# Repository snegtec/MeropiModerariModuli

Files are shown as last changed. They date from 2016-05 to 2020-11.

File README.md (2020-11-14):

/*****************************************************************************
*
* MEROPI MODERARI MODULI
* a simple microcontroller system for controlling light output of linear 
* fluorescent tube according to saved program
* 
* version: 0.3 (November 2020)
* author: Erik Kos
*   snegtec.com
*   snegtec@outlook.com
* 
* Copyright (c) 2014-2020 Erik Kos
* License:
*   application, source code - GNU General Public License
*   hardware (schematics, pcb design) - Creative Commons Attribution 
*   Share-Alike license (CC BY-SA 4.0)
* 
****************************************************************************/

Used tools
* compiler: Atmel Studio 6
* application for pcb design: Eagle 6.5.0.

Notes
* this is a beta version!
* pcb for power and relay modules are one-sided; you can create it cheaper than 2 sided versions.

Important note!
* The power module use 230V. There could requirements in your country about design and electrical rules for design of such devices. If you are not confident when working with such voltages don't use the power module. Use ready power supply. 

TODO
* it is better to use external oscilator
* it would be good idea to add socket for serial (txd, rxd); for example during reset Bluetooth connection is lost; it is not a problem in final, production environment but during debug it bothers;
* holes for mounting the boards could have bigger diameter
* cloud events hasn't been tested too carefully; only PWM1 pin has support for cloud events
* no support for daylight saving time 
* add more meaningful captions for elements on pcb boards; like 5V or 3,3V instead of X5 or X3;

Bugs
* There is support for bigger buffer for transmission of AT commands. But sometimes there is a problem that the end of the line disapears when parsed.

Bootloader information
* My version of module uses ATMEL AVR UART Bootloader for AVR-GCC/avr-libc. It is not needed for modules to work. But it can be very helpful to update software when a final module is mounted in a place where there is difficult access.

* MMM software has support for butterfly compatible programmer. It allows for touchless programming of the module. No need to press any button before programming the device. Programmer needs just to use Bluetooth serial port. You start programming, the module resets and bootloader loads into memory and loads new program to memory. More info in utils_com.c file on line 536.

More information about bootloader:
* ATMEL AVR UART Bootloader for AVR-GCC/avr-libc
* by Martin Thomas, Kaiserslautern, Germany
* mthomas@rhrk.uni-kl.de
* eversmith@heizung-thomas.de
* http://www.siwawi.arubi.uni-kl.de/avr_projects

/****************************************************************************/

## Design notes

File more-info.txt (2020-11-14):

/****************************************************************************/

Meropi Moderari Moduli

Simple microcontroller system for controlling light output of linear fluorescent tube according to saved program
Introduction

I needed a way for adjusting the output of light of linear fluorescent tubes. I needed a system which allows me to program light level for specified hour. It had to be a system for simulating day. For example: at 6 o'clock the light is enabled but is weak. So up to 8 o'clock the light level rises slowly and it stays at specified value until 18 o'clock. Then it diminishes. And at 20 o'clock the light is turn off.

So what I really wanted was a computer system. There weren't any market solution which suits me. The current existing systems was costly, difficult to use or limited. I decided to create my own solution. I chose to use din enclosures. It is tidy and clean way for electronic to be contained within. No need to design special boxes and cut holes in it. Usually fluorescent tubes don't diminish the light by itself. So I needed a special electronic ballast with function to reduce the light level. The chosen one used common 1-10V system.

I like systems which are flexible and easy to use. I am a programmer so I am not limited to "(not) easy to use" user's interfaces. I wanted a system created by a programmer for use by a programmer. Why add physical buttons, lcd displays if there is much simpler solution? I used Bluetooth connectivity with its Serial Port Profile. This is the most simple and effective solution. Because a device can be controlled by Android phone or notebook. It gives possibility to make advanced functions with keeping in mind real easiness of software controls like buttons, radio and check boxes, edit boxes, lists and even sliders. And creating sophisticated desktop/mobile application is usually much simpler than creating traditional user interface with buttons, lcd displays and led diodes. 
Hardware

The hardware is divided into 3 din units. There is special control unit. It contains microcontroller (ATmega328P) with some additional components: micro-sd socket, real time clock (PCF8563) and HC05 bluetooth module which is connected with serial port of microcontroller. Micro-sd socket was added as a way of expanding memory for data. But it is not used in this application. There is 14 input/output lines. Some of them can be used as SPI and I2C lines. Four of them are used as PWM channels.

The second din unit serves as a power unit. It is equipped with transformer which lowers voltage. It provides 3 lines of voltage: double 5V and 3,3V thanks of two 78L05F and TS520533 voltage regulators. The third unit contains two relays and two special voltage regulators. 1-10V electronic ballasts are driven by them. All connections are done with 3,5mm terminal blocks. Relays use 5mm terminal blocks. So during assembly in final din box there is no need to use solder iron - just a screwdriver.
Electronics inside
Software

First programming of the central unit has to be done with standard ISP programmer. There was added a bootloader so all next software updates can be made using Bluetooth. Modules may be mounted in place where there is no easy access. So there is no need to press a button (or do something else on device) to enable to upload new software - just restart the module and upload new software.

To use the device there is need to enter user defined set of on/off events. The default method uses terminal emulator. The user sends special AT commands to program date, time, events and lists previously programmed events or clear them. As of time of creating the solution I decided to not create special desktop application for a user. For me it was enough, and very comfortable to use terminal emulator. AT commands are good link between a microcontroller system and application with a graphical user interface. So I have just created simplified Android application. It enables a user to control level of light and there is possible to turn on and off light with a mobile phone.
The application for Android phones
Other features

Finally, I added so called cloud events to the system. If a cloud covers Sun there is a smaller amount of light. But the clouds aren't usually uniform. So the light level changes constantly. Sometimes there are more clouds in the sky and sometimes there are just few clouds on it. So the cloud events simulate the light level change during cloudy day.

Possible uses for such device are: light control, light control for an aquarium or a terrarium, industry applications, data gathering with wireless download and probably many others.
Din modules
Additional information

Used fluorescent tubes were: OSRAM Lumilux T5 HE 880

with 1-10V dimmable starter: b,a,g, BCD35.2F-01/220-240/1-10V
Examples of AT commands

set time

AT+TIME=15:28:00

check what date is on the device

AT+DATE?

List all on/off/pwm (cloud) events

AT+PRINT_EVENTS

clear events

AT+CLEAR_EVENTS

set EXP0 pin output enabled and PWM0 pin output to 127 (50%)

AT+EXP0=1&PWM0=127

add a program and enable automatic (events) mode

AT+ADD=EXP0;0830;HIGH&ADD=PWM0;0830;0;100;60&ADD=PWM0;2050;100;-100;60&ADD=EXP0;2130;LOW&EVENT_MODE

Copyright (c) 2014-2020 Erik Kos

/****************************************************************************/

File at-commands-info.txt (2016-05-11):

	************
	* Information commands

command: AT
response: OK

command: AT+MEROPE
response: MEROPE OK

	************
	* time&date commands

command: AT+DATE?
response: current date set on device

command: AT+TIME?
response: current time set on device

	Setting time and date

command: AT+DATE=YYYY/MM/DD/W_D
example: AT+DATE=2014/10/29/3
year - 4 digits, month and day are 2 digits, week_day is 1 digit

command: AT+DATE=2014/02/07/0
20141029 => wednesday => week_day == 3

command: AT+TIME=HH:MM:SS
example: AT+TIME=21:14:45
always 2 digits for every number: AT+TIME=03:05:07

	************
	* setting pins manually

Set pin EXP0 to high state
command: AT+EXP0=1

Set pin EXP0 to low state
command: AT+EXP0=0

Set PWM0 pin to 45% (pulse width modulation)
AT+PWM0=45

Set PWM0 pin to 100% (100% really means this pin is just high)
AT+PWM0=100

	************
	* event commands

Set device to manual mode. Device's pins are set manually without using a program.
command: AT+MANUAL_MODE

Set device to automatic (events) mode; Device pins are set automatically according to a program on a device.
command: AT+EVENT_MODE

Prints all events
command: AT+PRINT_EVENTS

Clear all events
command: AT+CLEAR_EVENTS

	************
	* adding events

These are commands used to add events to a memory. 

For adding commands it is important to set manual mode and clear earlier events:
command: AT+MANUAL_MODE&CLEAR_EVENTS

Add entry: set EXP0 pin to high at 8:30 every morning
command: ADD=EXP0;0830;HIGH

Add PWM event
command: AT+ADD=pwm_pin;start_time;start_value;end_value;duration
example: AT+ADD=PWM0;0830;0;100;60
explanation: for PWM0 start at 8:30 at 0% and increase pwm value to 100% in 60 minutes
note: duration is always minute; 

Add negative PWM event
if you want to decrease value use negative value
command: ADD=PWM0;1930;100;-100;60
explanation: for PWM0 start at 1930 at 100% and decrease pwm value 100% below current in 60 minutes

	Important information

Note: Added events has to be sorted by time.

This is ok (first event at 10:00, later event at 12:30)
AT+ADD=EXP0;1000;HIGH&ADD=EXP0;1230;LOW

This is wrong
AT+ADD=EXP0;1230;LOW&ADD=EXP0;1000;HIGH

	************
	* Example program:

This is an example program. It is used to control light level of fluorescent tube. A relay used to enable/disable power is controlled by EXP0 pin of MMM module. The light level is controlled by driving the circuit by PWM0 pin of the module.

The program: 
 - the light slowly increases from dark to full light in one hour between 8:30 and 9:30
 - the light level is 100% between 9:30 and 19:30
 - the light is dimmed from 100% to 0% between 19:30 and 20:30
 - the light is disabled between 20:30 (evening) and 8:30 (morning)
 - if you restart device during program, it always checks what is the current mode

Note: You may enter several commands at once. But char buffer is limited so don't add too long commands.

AT+ADD=EXP0;0830;HIGH&ADD=PWM0;0830;0;100;60&ADD=PWM0;1930;100;-100;60&ADD=EXP0;2030;LOW&EVENT_MODE

	What does the program do?

beginning of every AT command
command: AT+

set pin EXP0 to high
command: ADD=EXP0;0830;HIGH

set PWM0 pin to: 0% at 8:30 and in 60 minutes increase to 100%
command: ADD=PWM0;0830;0;100;60

set PWM0 pin to 100% at 19:30 and in 60 minutes decrease it to 0% 
command: ADD=PWM0;1930;100;-100;60

set EXP0 pin to low state
command: ADD=EXP0;2030;LOW

enable event mode (runs the program)
command: EVENT_MODE

	************
	* cloud events

command: AT+CLOUD=pin;time;pin_state;duration;final_state
example: AT+CLOUD=PWM1;1530;30;50;30

	************
	* other commands

get and reset VL_BIT (in PCF8563)
command: AT+GET_VL
response: status of VL_BIT

command: AT+RESET_VL
response: resets VL_BIT

	************
	* Control commands

command: AT+RESET
response: reset of device

	************
	* HC-05 configuration

Note: AT+PASS=AT+COMMAND passes AT commands directly to HC-05 BT

command: AT+PASS=AT+PSWD=1357

default pswd: 1234

Change Bluetooth name
command: AT+PASS=AT+NAME=Merope

Get Bluetooth name:
command: AT+PASS=AT+NAME?

Other commands:

Passes AT command to HC-05
command: AT+PASS=AT

Get state of HC-05
command: AT+PASS=AT+STATE?

Get version of HC-05
command: AT+PASS=AT+VERSION?

	************

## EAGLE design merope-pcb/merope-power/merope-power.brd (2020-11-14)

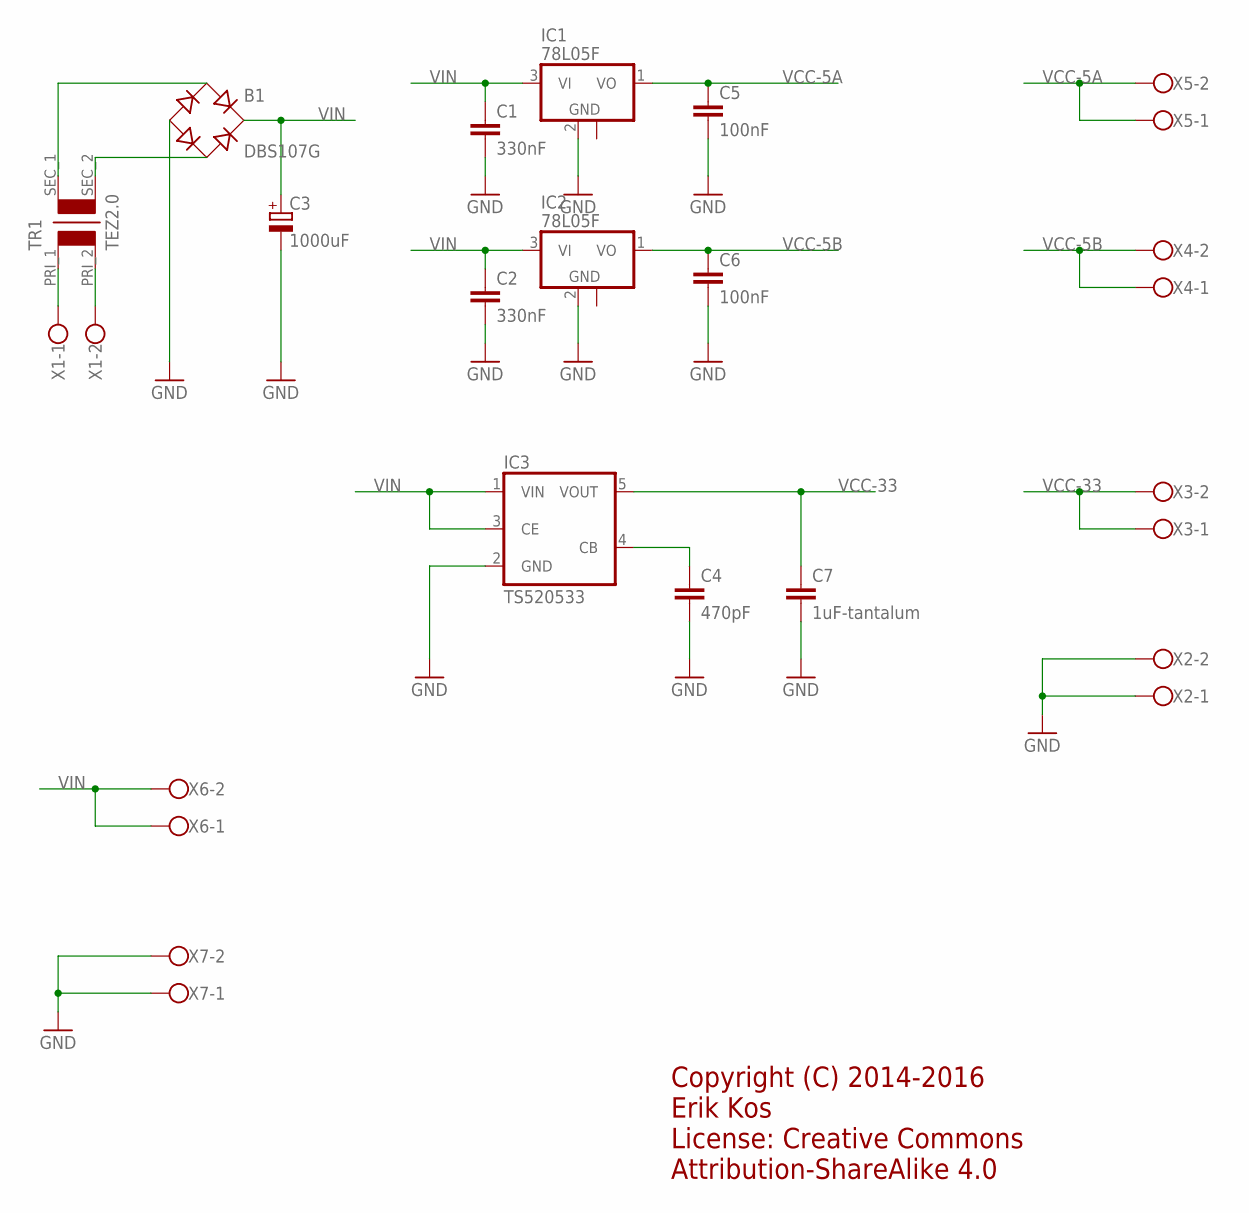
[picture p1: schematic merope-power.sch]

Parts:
B1: DBS107G; DBS
C1, C2: 330nF; C0805
C3: 1000uF; TT5D11
C4: 470pF; C0805
C5, C6: 100nF; C0805
C7: 1uF-tantalum; C0805
IC1, IC2: 78L05F; SOT89
IC3: TS520533; SOT25
TR1: TEZ2.0
X1: TERMINAL_BLOCK_5_2
X2, X3, X4, X5, X6, X7: TERMINAL_BLOCK_35_2

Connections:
GND: B1.-, C1.2, C2.2, C3.-, C4.2, C5.2, C6.2, C7.2, IC1.2 (GND), IC2.2 (GND), IC3.2 (GND), X2.1, X2.2, X7.1, X7.2
unnamed: B1.AC1, TR1.SEC_1
unnamed: C4.1, IC3.4 (CB)
unnamed: B1.AC2, TR1.SEC_2
unnamed: TR1.PRI_1, X1.1
unnamed: TR1.PRI_2, X1.2
VCC-5A: C5.1, IC1.1 (VO), X5.1, X5.2
VCC-5B: C6.1, IC2.1 (VO), X4.1, X4.2
VCC-33: C7.1, IC3.5 (VOUT), X3.1, X3.2
VIN: B1.+, C1.1, C2.1, C3.+, IC1.3 (VI), IC2.3 (VI), IC3.1 (VIN), IC3.3 (CE), X6.1, X6.2

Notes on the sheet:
Copyright (C) 2014-2016 Erik Kos License: Creative Commons Attribution-ShareAlike 4.0

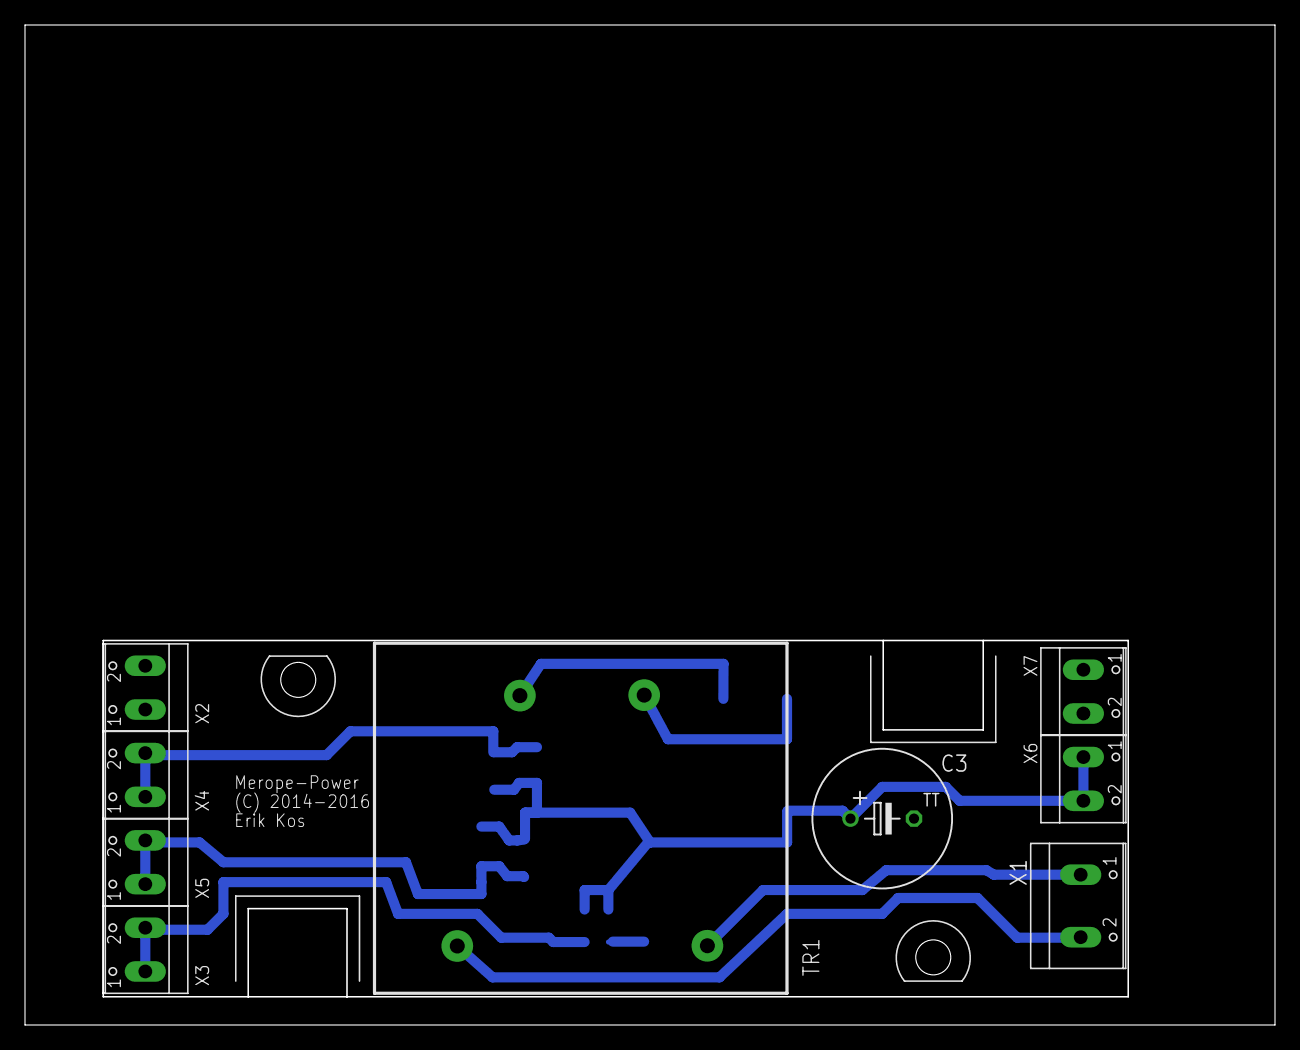
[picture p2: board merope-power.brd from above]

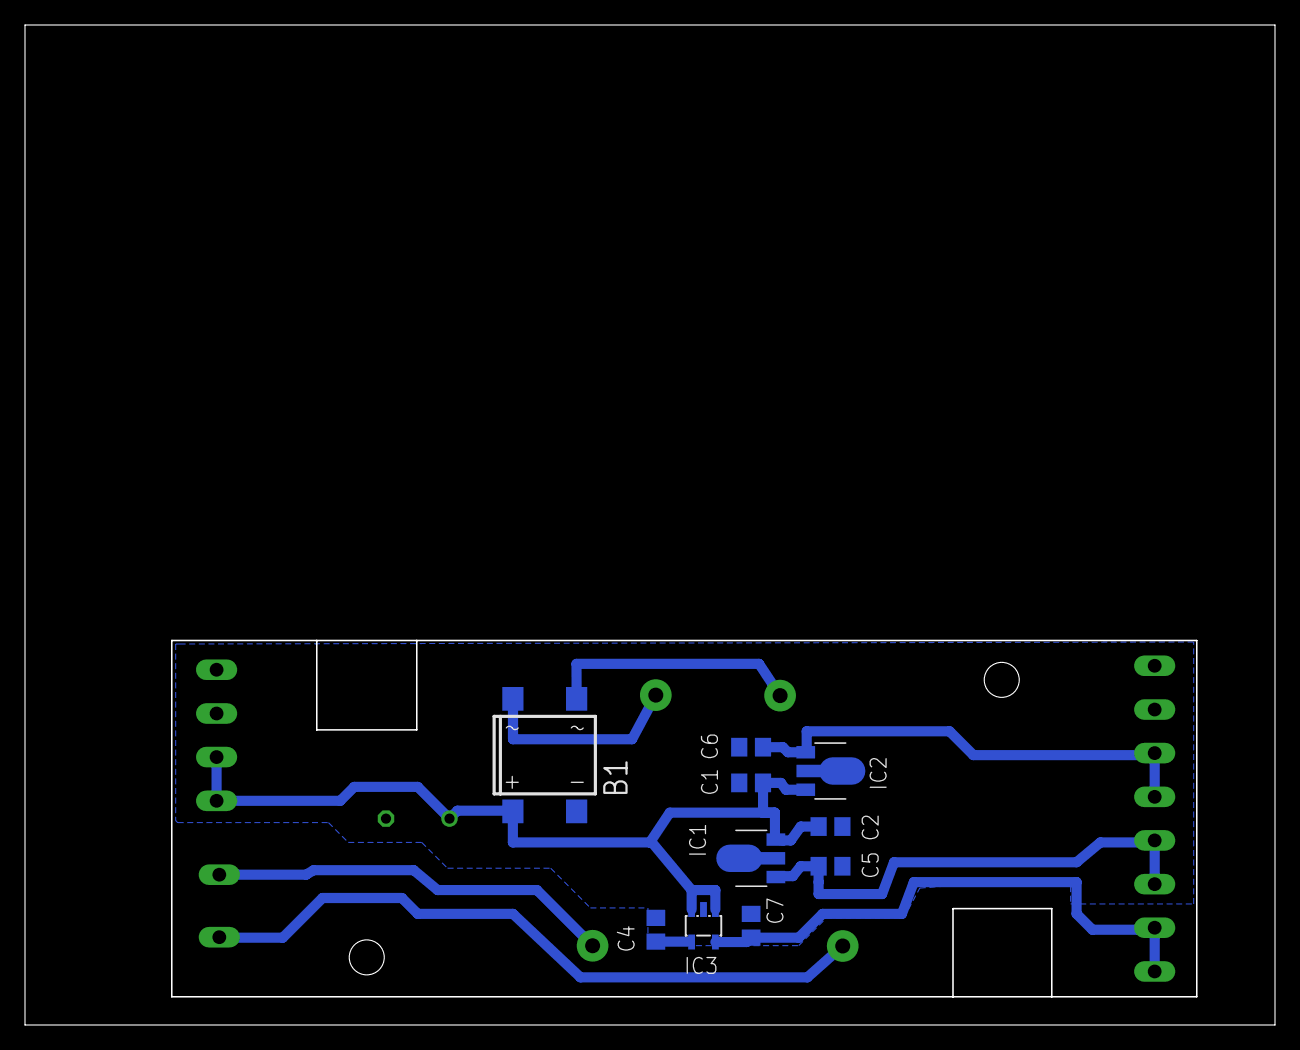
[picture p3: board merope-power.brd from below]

Board: 2 copper layers, 100.0 x 80.0 mm, 20 parts (10 on the bottom side), 10 nets.

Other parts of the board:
U$1: Z-103

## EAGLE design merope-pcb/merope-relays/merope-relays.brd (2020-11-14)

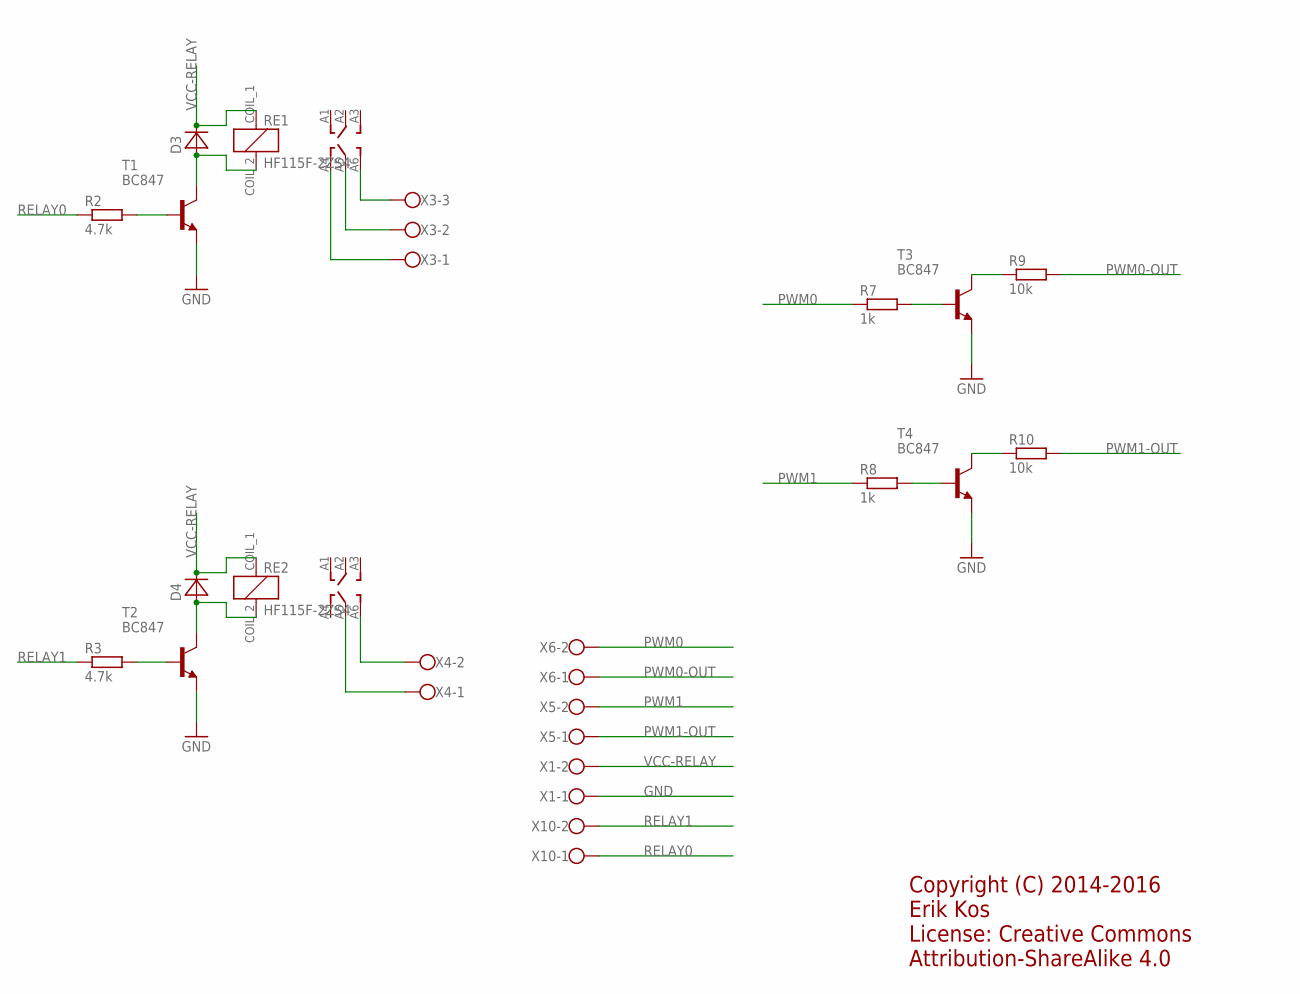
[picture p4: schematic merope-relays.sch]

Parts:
D3, D4: DIODE_0805; R0805
R2, R3: 4.7k; M0805
R7, R8: 1k; M0805
R9, R10: 10k; M0805
RE1, RE2: HF115F-2ZS4; HF115F
T1, T2, T3, T4: BC847; SOT23-BEC
X1, X5, X6, X10: TERMINAL_BLOCK_35_2
X3: TERMINAL_BLOCK_5_3
X4: TERMINAL_BLOCK_5_2

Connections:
GND: T1.E, T2.E, T3.E, T4.E, X1.1
unnamed: RE2.A6, X4.2
unnamed: R2.2, T1.B
unnamed: RE1.A6, X3.3
unnamed: RE1.A5, X3.2
unnamed: D3.1 (A), RE1.COIL_2, T1.C
unnamed: RE2.A5, X4.1
unnamed: RE1.A4, X3.1
unnamed: R3.2, T2.B
unnamed: D4.1 (A), RE2.COIL_2, T2.C
unnamed: R7.2, T3.B
unnamed: R9.1, T3.C
unnamed: R8.2, T4.B
unnamed: R10.1, T4.C
PWM0: R7.1, X6.2
PWM0-OUT: R9.2, X6.1
PWM1: R8.1, X5.2
PWM1-OUT: R10.2, X5.1
RELAY0: R2.1, X10.1
RELAY1: R3.1, X10.2
VCC-RELAY: D3.2 (C), D4.2 (C), RE1.COIL_1, RE2.COIL_1, X1.2

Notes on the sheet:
Copyright (C) 2014-2016 Erik Kos License: Creative Commons Attribution-ShareAlike 4.0

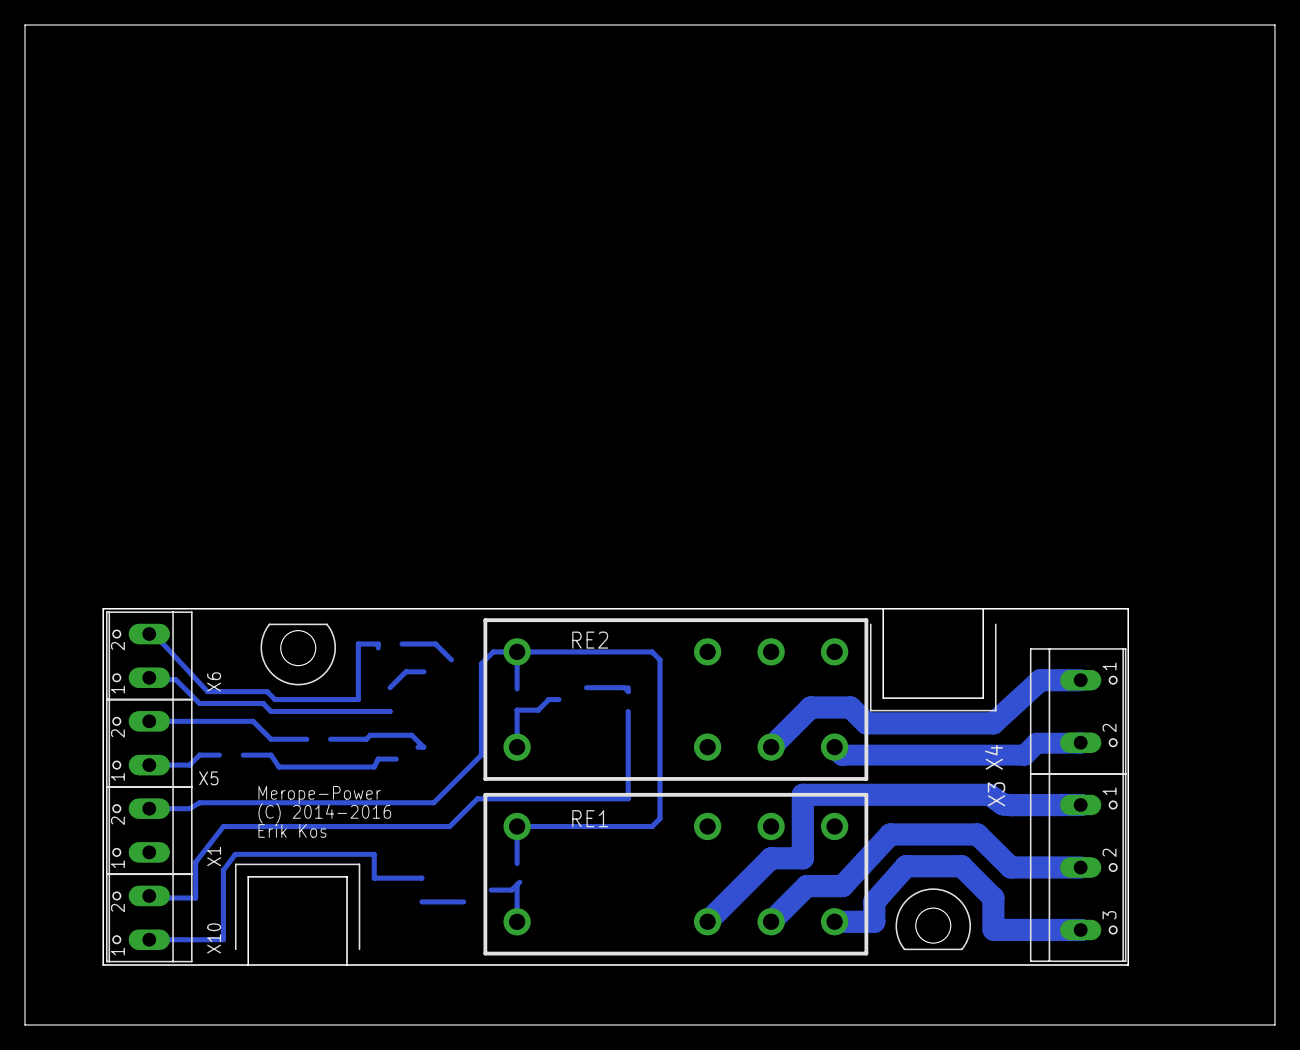
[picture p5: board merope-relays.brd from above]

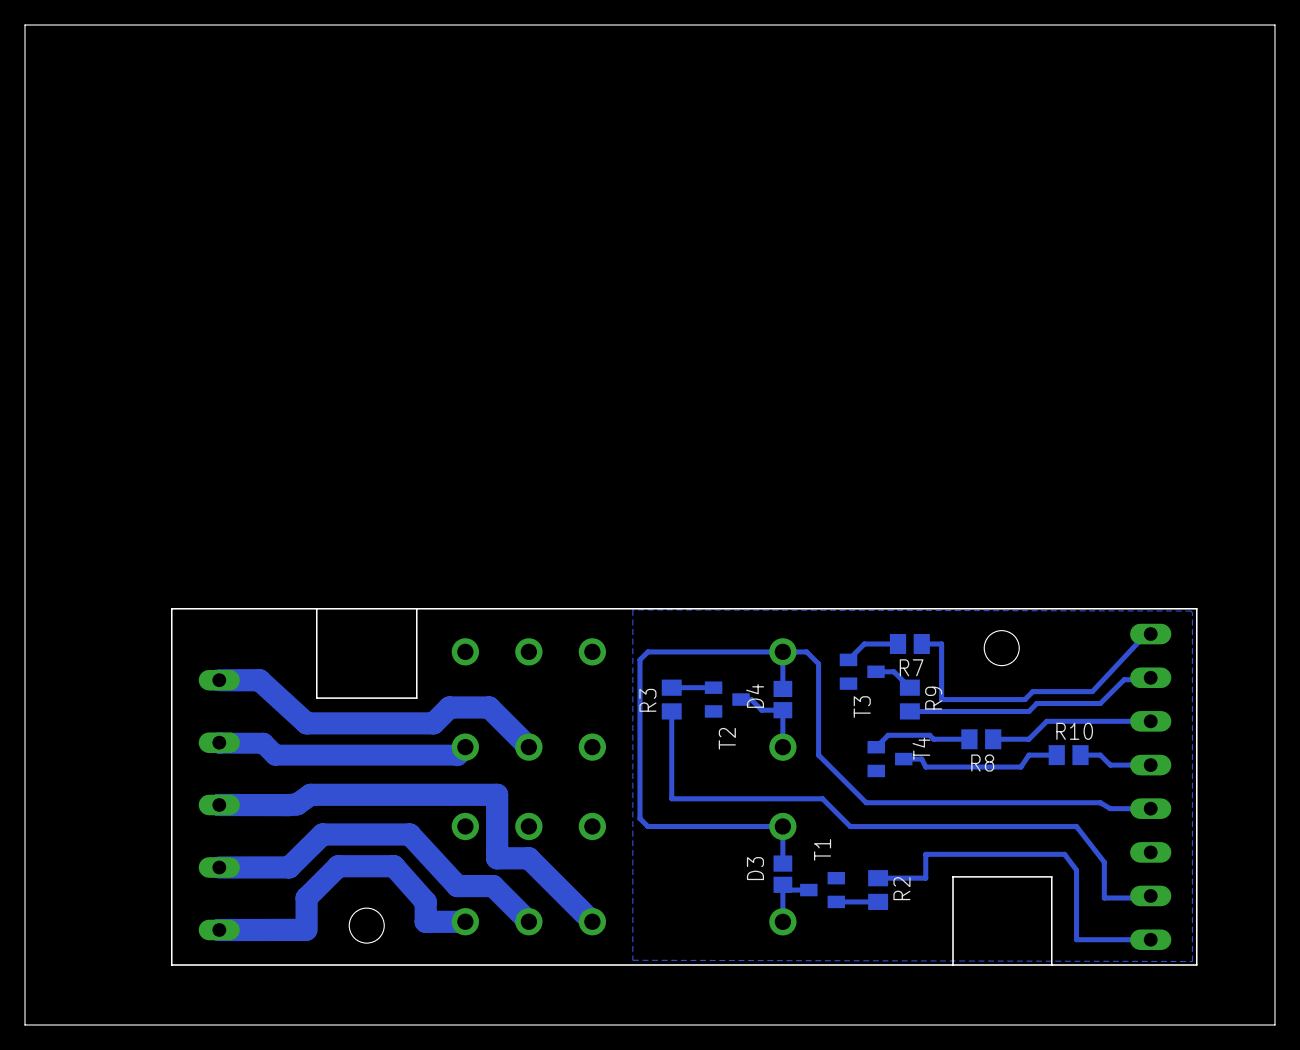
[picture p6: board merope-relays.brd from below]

Board: 2 copper layers, 100.0 x 80.0 mm, 21 parts (12 on the bottom side), 21 nets.

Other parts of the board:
U$1: Z-103

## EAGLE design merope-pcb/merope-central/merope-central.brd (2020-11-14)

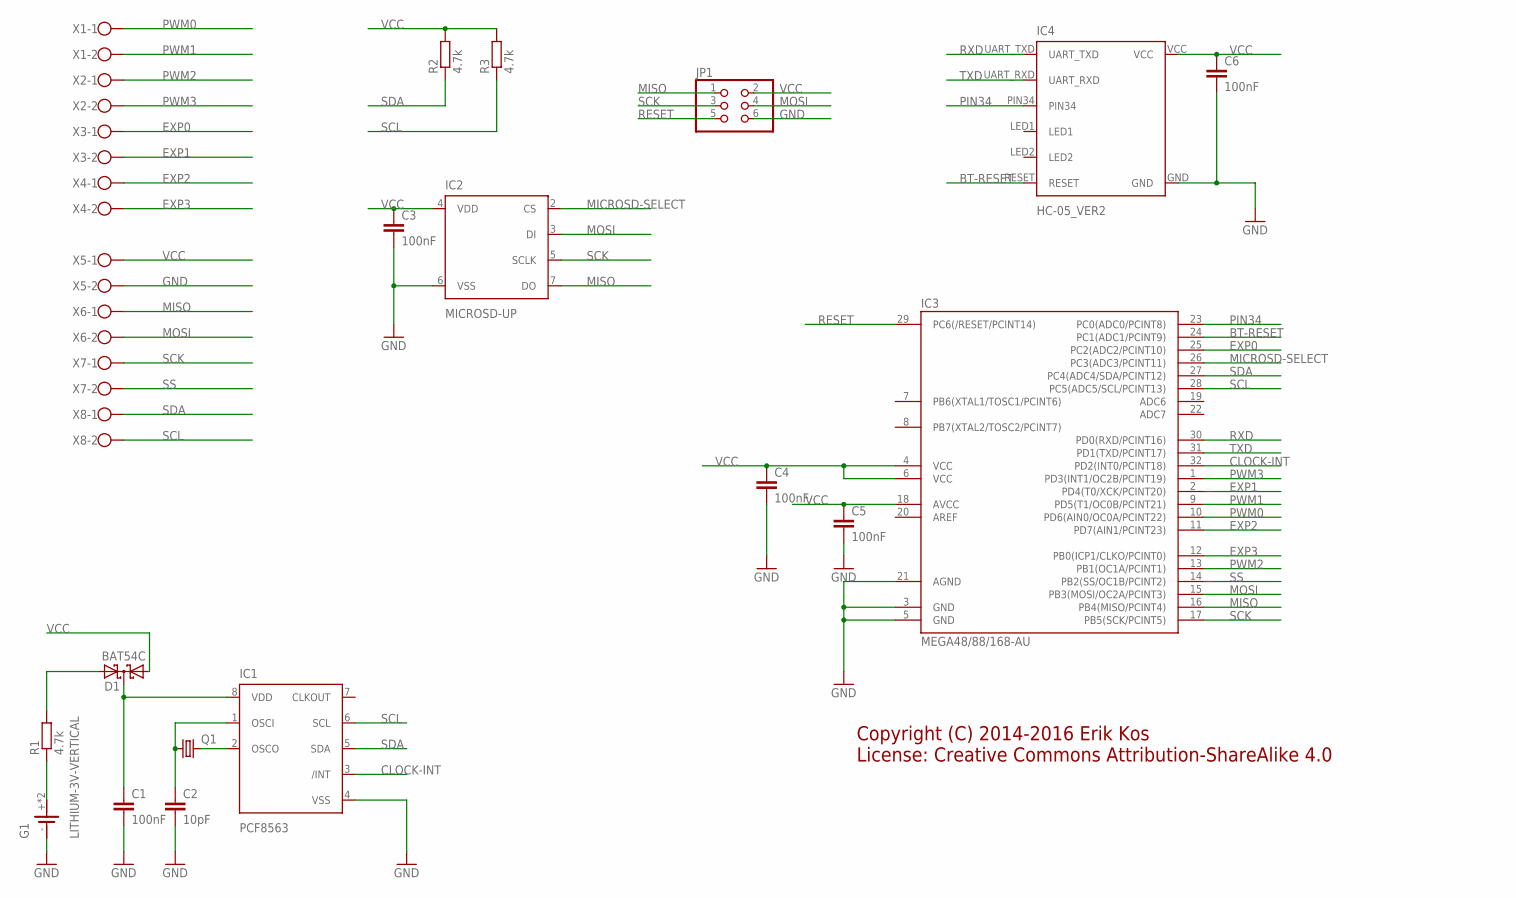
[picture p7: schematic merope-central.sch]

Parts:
C1, C3, C4, C5, C6: 100nF; C0805
C2: 10pF; C0805
D1: BAT54C; SOT23
G1: LITHIUM-3V-VERTICAL
IC1: PCF8563; SO8
IC2: MICROSD-UP
IC3: MEGA48/88/168-AU; TQFP32-08
IC4: HC-05_VER2
JP1: PINHD-2X3; 2X03
Q1: CRYSTALTC26V; TC26V
R1, R2, R3: 4.7k; M0805
X1, X2, X3, X4, X5, X6, X7, X8: TERMINAL_BLOCK_35_2

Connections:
BT-RESET: IC3.24 (PC1(ADC1/PCINT9)), IC4.RESET
CLOCK-INT: IC1.3 (/INT), IC3.32 (PD2(INT0/PCINT18))
EXP0: IC3.25 (PC2(ADC2/PCINT10)), X3.1
EXP1: IC3.2 (PD4(T0/XCK/PCINT20)), X3.2
EXP2: IC3.11 (PD7(AIN1/PCINT23)), X4.1
EXP3: IC3.12 (PB0(ICP1/CLKO/PCINT0)), X4.2
GND: C1.2, C2.2, C3.2, C4.2, C5.2, C6.2, G1.-, IC1.4 (VSS), IC2.6 (VSS), IC3.3 (GND), IC3.5 (GND), IC3.21 (AGND), IC4.GND, JP1.6, X5.2
MICROSD-SELECT: IC2.2 (CS), IC3.26 (PC3(ADC3/PCINT11))
MISO: IC2.7 (DO), IC3.16 (PB4(MISO/PCINT4)), JP1.1, X6.1
MOSI: IC2.3 (DI), IC3.15 (PB3(MOSI/OC2A/PCINT3)), JP1.4, X6.2
unnamed: C1.1, D1.3 (CC), IC1.8 (VDD)
unnamed: G1.+, G1.+1 (+), R1.1
unnamed: D1.2 (A2), R1.2
unnamed: IC1.2 (OSCO), Q1.2
unnamed: C2.1, IC1.1 (OSCI), Q1.1
PIN34: IC3.23 (PC0(ADC0/PCINT8)), IC4.PIN34
PWM0: IC3.10 (PD6(AIN0/OC0A/PCINT22)), X1.1
PWM1: IC3.9 (PD5(T1/OC0B/PCINT21)), X1.2
PWM2: IC3.13 (PB1(OC1A/PCINT1)), X2.1
PWM3: IC3.1 (PD3(INT1/OC2B/PCINT19)), X2.2
RESET: IC3.29 (PC6(/RESET/PCINT14)), JP1.5
RXD: IC3.30 (PD0(RXD/PCINT16)), IC4.UART_TXD
SCK: IC2.5 (SCLK), IC3.17 (PB5(SCK/PCINT5)), JP1.3, X7.1
SCL: IC1.6 (SCL), IC3.28 (PC5(ADC5/SCL/PCINT13)), R3.1, X8.2
SDA: IC1.5 (SDA), IC3.27 (PC4(ADC4/SDA/PCINT12)), R2.1, X8.1
SS: IC3.14 (PB2(SS/OC1B/PCINT2)), X7.2
TXD: IC3.31 (PD1(TXD/PCINT17)), IC4.UART_RXD
VCC: C3.1, C4.1, C5.1, C6.1, D1.1 (A1), IC2.4 (VDD), IC3.4 (VCC), IC3.6 (VCC), IC3.18 (AVCC), IC4.VCC, JP1.2, R2.2, R3.2, X5.1

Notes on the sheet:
Copyright (C) 2014-2016 Erik Kos License: Creative Commons Attribution-ShareAlike 4.0

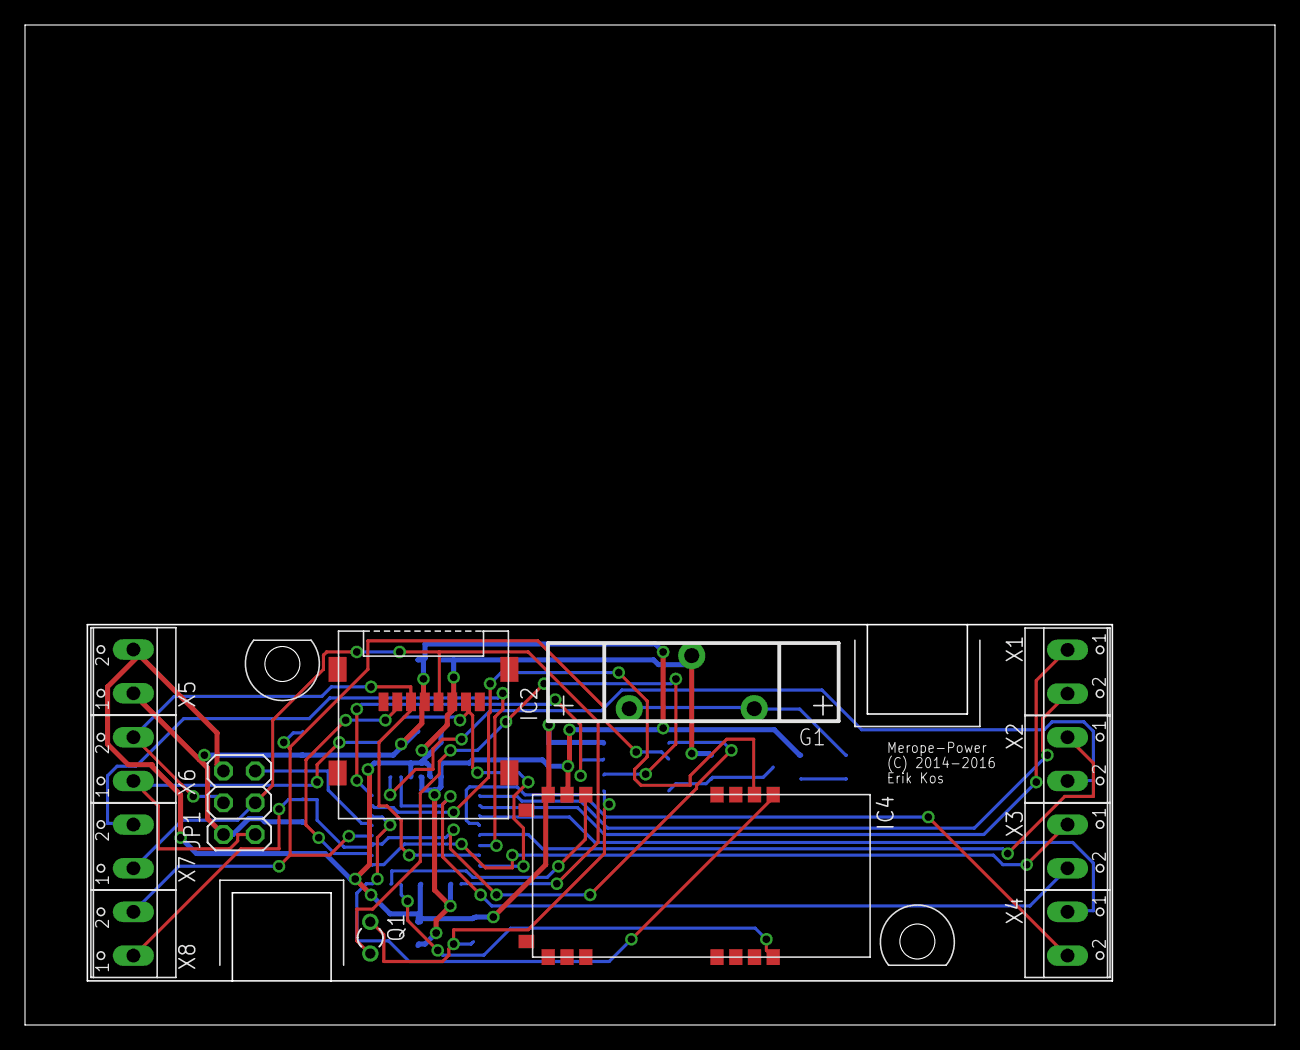
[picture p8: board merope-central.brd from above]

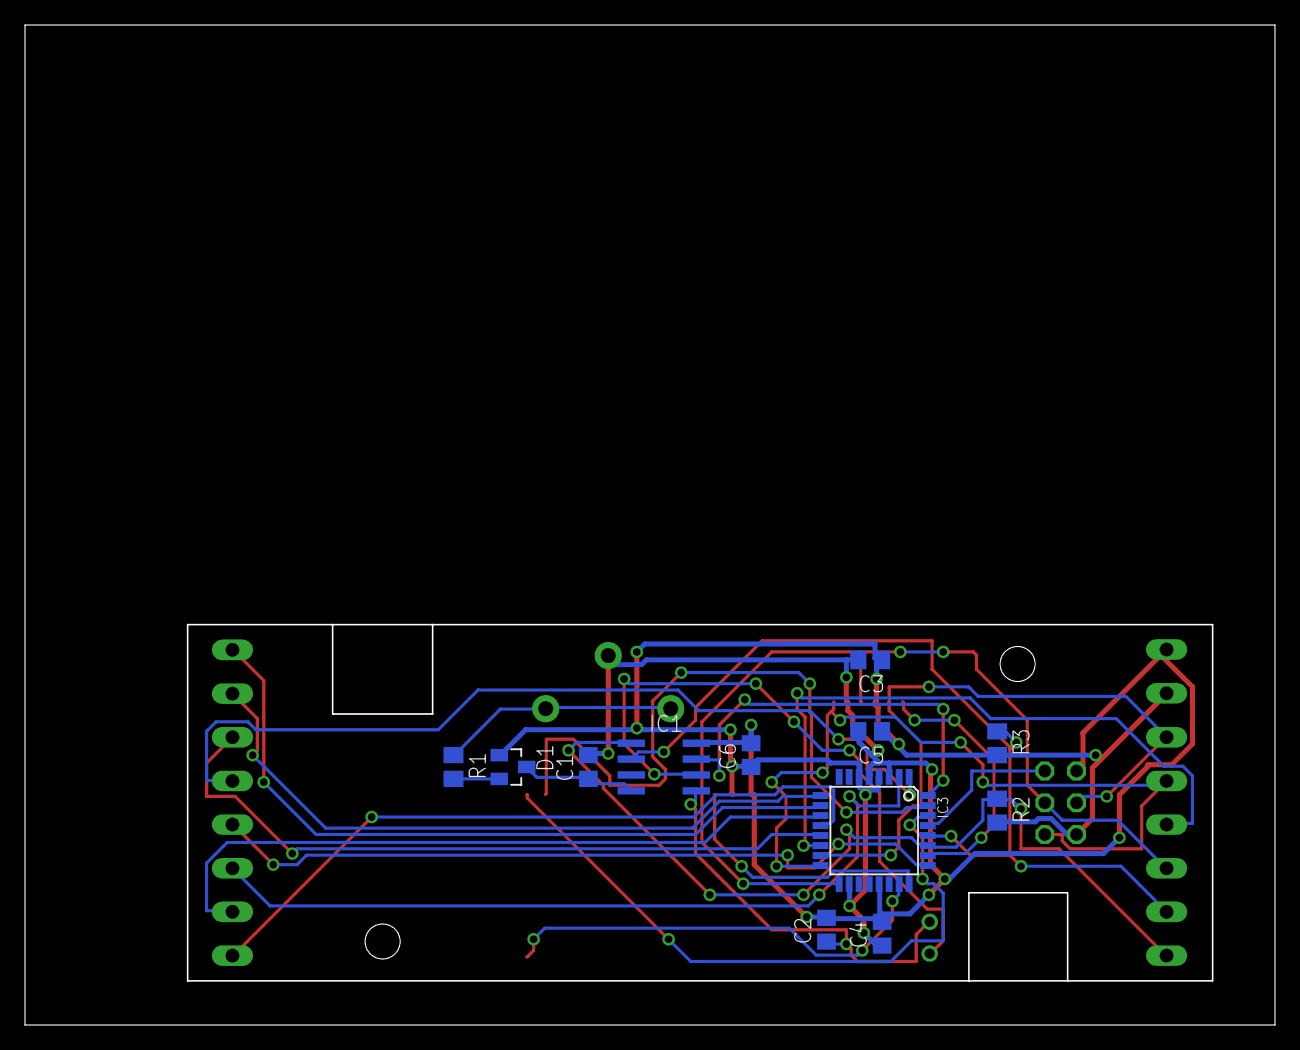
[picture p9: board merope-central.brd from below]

Board: 2 copper layers, 100.0 x 80.0 mm, 26 parts (12 on the bottom side), 28 nets.

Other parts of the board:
U$1: Z-103

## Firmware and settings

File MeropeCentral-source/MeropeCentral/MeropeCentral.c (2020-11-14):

/*****************************************************************************
*
* MEROPI MODERARI MODULI
* a simple microcontroller system for controlling light output of linear 
* fluorescent tube according to saved program
*
* version: 0.2 (December 2017)
* compiler: Atmel Studio 6
* by       : Erik Kos
*          snegtec.com
*          snegtec@outlook.com
*
* License  : Copyright (c) 2014-2017 Erik Kos
* 
****************************************************************************
*
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
****************************************************************************/


/*
* MeropeCentral.c
*
* Created: 2014-10-06 17:20:05
*  Author: jck
*/

#include <string.h>
#include <avr/io.h>
#include <util/delay.h>
#include <avr/interrupt.h>
#include <util/twi.h>
#include <stdio.h>
#include <stdlib.h>
#include <avr/eeprom.h>
#include <avr/wdt.h>

#include "all_imports.h"
#include "utils_time.h"
#include "utils_com.h"
#include "utils_pwm.h"
#include "utils_twi.h"

/*
cpu frequency is defined in menu: Project/...properties/Toolchain/AVR/GNU C compiler/Symbols/F_CPU=1000000UL
cpu freqency is set by fuse bits not by definition by F_CPU; F_CPU is needed by delay.h; ckdiv8 is also set
*/

void initialize_app()
{
	// init i2c
	twi_init();
	
	// disable BT reset (it is connected to PC1 pin ATMega328P)
	// set pin as output
	DDRC |= (1 << DDC1);
	
	// set high state
	PORTC |= (1 << DDC1);
	
	
	// pin34 - for disabling AT mode for BT
	// it is connected to PC0
	// set pin as output
	DDRC |= (1 << DDC0);
	
	// set low state
	PORTC &=~ (1 << DDC0);
	
	// set params for usart
	// 9600N81 - 9600, no parity, 8 data bits, 1 stop bit
	USART_Init();
	
	// set as output
	DDRD |= (1 << DDD5);

	char String[] = "start ";
	send_string(String);
	send_string("\r\n");
	
	setup_pwm();
	
	// enable interrupts
	SREG |= (1 << 7);
}

/*
Resets device
*/
void reset()
{
	// set up watchdog timer
	wdt_enable(WDTO_250MS);
}

int main(void)
{
	// disable watchdog timer
	MCUSR = 0;
	wdt_disable();
	
	initialize_app();
	
	// check VL bit in PCF8563
	if (get_vl())
	send_string("Replace backup battery and clear VL bit!!!\r\n");
	
	load_events();
	
	while(1)
	{
		// additional timer event
		_delay_ms(5000);
		timer_event();
		
	}
	
}

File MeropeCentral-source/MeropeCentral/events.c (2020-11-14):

/*****************************************************************************
*
* MEROPI MODERARI MODULI
* a simple microcontroller system for controlling light output of linear
* fluorescent tube according to saved program
*
* version: 0.2 (December 2017)
* compiler: Atmel Studio 6
* by       : Erik Kos
*          snegtec.com
*          snegtec@outlook.com
*
* License  : Copyright (c) 2014-2017 Erik Kos
*
****************************************************************************
*
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
****************************************************************************/

#include <string.h>
#include <avr/io.h>
#include <util/delay.h>
#include <avr/interrupt.h>
#include <util/twi.h>
#include <stdio.h>
#include <stdlib.h>
#include <avr/eeprom.h>

#include "all_imports.h"
#include "utils_time.h"
#include "utils_com.h"
#include "utils_pwm.h"
#include "utils.h"

// event type
enum {EXP, PWM, CLOUDS};

/*
Important!
Clear all events (in EEPROM) after changing format of this struct!
*/
struct Event
{
	// pin number of port (for relay and pwm)
	// exact number of pin is declared below
	uint8_t pin;
	int32_t time;
	uint8_t type;
	
	// disable == 0, enable == 1; for pwm events it is start value
	int8_t pin_state; 
	
	// how much time it has to take dimming or lighting
	int32_t duration; 
	
	// how much increment or decrement value for specified time (in time field)
	int8_t inc; 
	
	int32_t temp_time;
	int32_t temp_duration;
	
	// final pin_state
	uint8_t final_state; 
	
};

#define EVENTS_SIZE 20

EEMEM struct Event events_ee[EVENTS_SIZE];

// how many events are saved
EEMEM uint8_t events_count_ee;

// ram versions
struct Event events[EVENTS_SIZE];
uint8_t events_count = -1;

// merope-central outputs/inputs
// pd 3, 4, 5, 6, 7, pb 0, 1, pc 2
// these are indices in actual_events[] array

// number of event for specified pin; which is currently active
enum {PIN_DISABLED = -2, NO_EVENT_YET = -1};

int8_t actual_events[8] = {PIN_DISABLED, PIN_DISABLED, PIN_DISABLED, PIN_DISABLED, PIN_DISABLED, PIN_DISABLED, PIN_DISABLED, PIN_DISABLED};

uint8_t event_mode = EVENT_MODE;

uint8_t get_event_mode() {
	return event_mode;
}

void set_manual_mode()
{
	event_mode = MANUAL_MODE;
}

void set_event_mode()
{
	event_mode = EVENT_MODE;
	load_events();
}

int what_pin(char *value)
{
	if (strcmp(value, "EXP0") == 0)
	return EXP0_PC2;
	else if (strcmp(value, "EXP1") == 0)
	return EXP1_PD4;
	else if (strcmp(value, "EXP2") == 0)
	return EXP2_PD7;
	else if (strcmp(value, "EXP3") == 0)
	return EXP3_PB0;
	else if (strcmp(value, "PWM0") == 0)
	return PWM0_PD6;
	else if (strcmp(value, "PWM1") == 0)
	return PWM1_PD5;
	else if (strcmp(value, "PWM2") == 0)
	return PWM2_PB1;
	else if (strcmp(value, "PWM3") == 0)
	return PWM3_PD3;
	
	return -1;
}

void add_event(int pin, int32_t time, int pin_state)
{
	// don't add if no space
	if (events_count >= EVENTS_SIZE - 1)
		return;
	
	events[events_count].pin = pin;
	events[events_count].time = time;
	events[events_count].pin_state = pin_state;
	
	switch(pin)
	{
		case EXP0_PC2:
		case EXP1_PD4:
		case EXP2_PD7:
		case EXP3_PB0:
		events[events_count].type = EXP;
		break;
		
		case PWM0_PD6:
		case PWM1_PD5:
		// not implemented yet case PWM2_PB1:
		// not implemented yet case PWM3_PD3:
		events[events_count].type = PWM;
		break;
		
		default:break;
	}

	events_count++;
	
	// save event to eeprom
	eeprom_busy_wait();
	eeprom_write_block(&events, &events_ee, sizeof(struct Event) * EVENTS_SIZE);
	
	// save count
	eeprom_busy_wait();
	eeprom_write_byte(&events_count_ee, events_count);
}

/*
Duration in minutes
*/
void add_pwm_event(int pin, int32_t time, int pin_state, int inc, int duration)
{
	// don't add if no place
	if (events_count >= EVENTS_SIZE - 1)
	return;
	
	events[events_count].pin = pin;
	events[events_count].time = time;
	events[events_count].pin_state = pin_state;
	events[events_count].inc = inc;
	events[events_count].duration = duration * 60;
	
	events[events_count].type = PWM;
	
	events_count++;
	
	// save event to eeprom
	eeprom_busy_wait();
	eeprom_write_block(&events, &events_ee, sizeof(struct Event) * EVENTS_SIZE);
	
	// save count
	eeprom_busy_wait();
	eeprom_write_byte(&events_count_ee, events_count);
}

/*
Duration in minutes
*/
void add_clouds_event(int pin, int32_t time, int pin_state, int duration, int final_state)
{
	// don't add if no place
	if (events_count >= EVENTS_SIZE - 1)
	return;
	
	events[events_count].pin = pin;
	events[events_count].time = time;
	events[events_count].pin_state = pin_state;
	events[events_count].duration = duration * 60; // convert to seconds
	events[events_count].final_state = final_state;
	
	events[events_count].type = CLOUDS;
	
	events_count++;
	
	// save event to eeprom
	eeprom_busy_wait();
	eeprom_write_block(&events, &events_ee, sizeof(struct Event) * EVENTS_SIZE);
	
	// save count
	eeprom_busy_wait();
	eeprom_write_byte(&events_count_ee, events_count);
}

/*
Search through events table and check are there any events for specified pin
if yes, change PIN_DISABLED => NO_EVENT_YET
*/
void prepare_actual_events()
{
	for (uint8_t a = 0; a < sizeof(actual_events); a++)
	{
		for (uint8_t i = 0; i < events_count; i++)
		{
			if (a == events[i].pin)
			{
				//change: PIN_DISABLED => NO_EVENT_YET
				actual_events[a] = NO_EVENT_YET;
				break;
			}
		}
	}
}

void add_default_events()
{
	struct Event tea[20];
	
	//***
	// clouds events
	
	// 0 event
	tea[0].pin = PWM1_PD5;
	tea[0].time = 0;
	tea[0].pin_state = 0;
	tea[0].type = PWM;
	
	// 1 event
	tea[1].pin = PWM1_PD5;
	tea[1].time = 5;
	tea[1].pin_state = 20;
	tea[1].duration = 50;
	tea[1].final_state = 20;
	tea[1].type = CLOUDS;
	
	// 2 event
	tea[2].pin = PWM1_PD5;
	tea[2].time = 55;
	tea[2].pin_state = 0;
	tea[2].type = PWM;
	
	// save event
	eeprom_busy_wait();
	eeprom_write_block(&tea, &events_ee, sizeof(struct Event) * EVENTS_SIZE);
	
	// save count
	events_count = 3;
	eeprom_busy_wait();
	eeprom_write_byte(&events_count_ee, events_count);
}
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

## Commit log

2016-05-11 full content
    full content - first public version
    [merope-central.brd, merope-central.sch, merope-power.brd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]
2017-12-05 20171205
    Some small bug fixes
    [MeropeCentral.c, events.c, utils_com.c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]
2020-11-14 Added some files and changed some information.
    [merope-central.brd, merope-central.sch, merope-power.brd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]

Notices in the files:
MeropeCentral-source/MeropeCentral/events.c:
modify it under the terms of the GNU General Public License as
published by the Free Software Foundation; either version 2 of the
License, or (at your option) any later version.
